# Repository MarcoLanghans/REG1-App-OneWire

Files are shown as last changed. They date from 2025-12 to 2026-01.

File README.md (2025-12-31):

Onewire Extension Card for OpenKNX REG1 BASE Device https://openknx.atlassian.net/wiki/spaces/OpenKNX/pages/7667822/OpenKNX+REG1+Basismodul (But you need the Case of the Universal Extension Version)
<br>
The Extension Card is no official created OpenKNX Hardware, so the usage is your personal risk. 
<br>
But it runs now since several days inside my person lab without any issues.

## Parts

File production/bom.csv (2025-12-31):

Designator | Footprint | Quantity | Value | LCSC Part #
C1, C10, C5, C6 | 0402 | 4 | 100nF
C2, C3, C4, C7 | 0402 | 4 | 10uF/6.3V | C15525
C8, C9 | 0402 | 2 | 0,1uF
D1 | DS9503P+ | 1 | DS9503P+ | C879660
D2 | D_SOD-323 | 1 | 1N5819WS | C191023
D4 | SOT-23-3 | 1 | ESDA5V3L | C502554
J1 | PinHeader_1x10_P2.54mm_Horizontal | 1 | REG1_App_Connector | C706873
R1, R11, R12, R3, R5, R6 | 0603 | 6 | 10K | C25804
R10, R9 | 0603 | 2 | 100 | C22775
R2, R4 | 0603 | 2 | 820 | C23253
R7, R8 | 0603 | 2 | 470 | C23179
U2 | SOT-23-5 | 1 | MIC2090-1YM5 | C625685
U3 | DS2484R+T | 1 | DS2484R+T | C124886
U4 | CA-IS3643HVW (C7422549) | 1 | CA-IS3643HVW
U5 | CA-IS3020G (C5156914) | 1 | CA-IS3020G

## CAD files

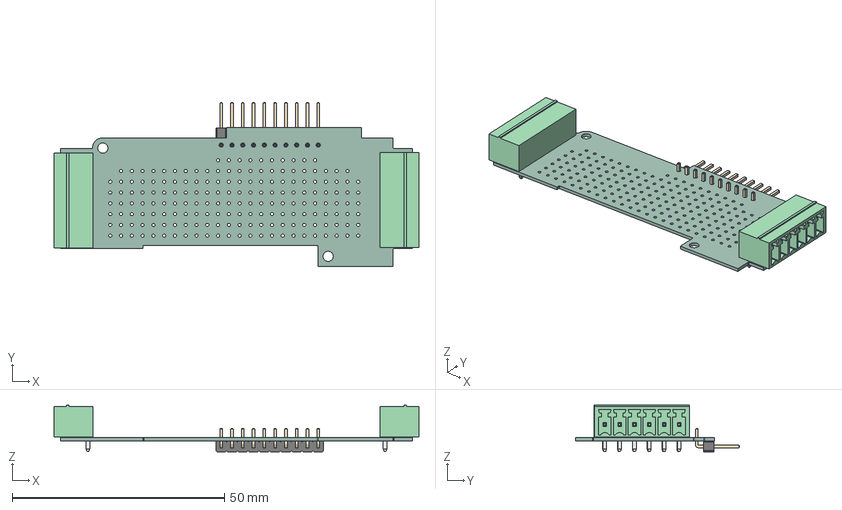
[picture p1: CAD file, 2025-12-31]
REG1-App-OneWire_V01.10.step
86.0 x 38.6 x 11.0 mm
MC_01x06_G_3_5mm x 2
PinHeader_1x10_P254mm_Horizontal
REG1-App-Universal_PCB

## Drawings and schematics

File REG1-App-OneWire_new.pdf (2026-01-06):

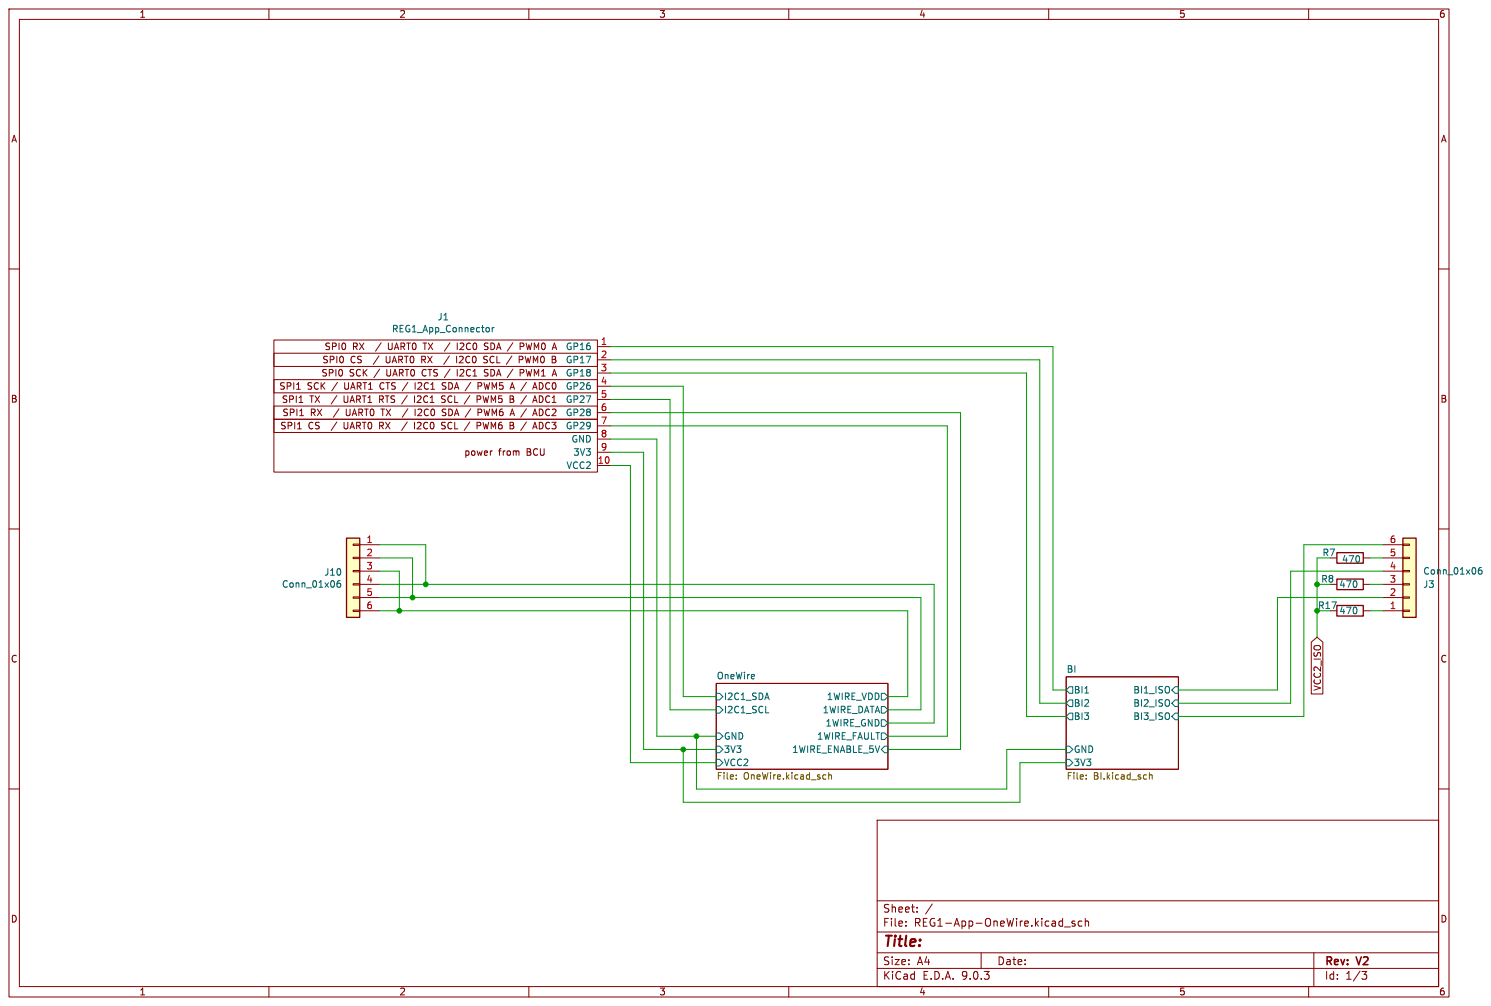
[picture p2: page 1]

Id: 1/3 Title: File: REG1-App-OneWire.kicad_sch Sheet: / 3V3 GND

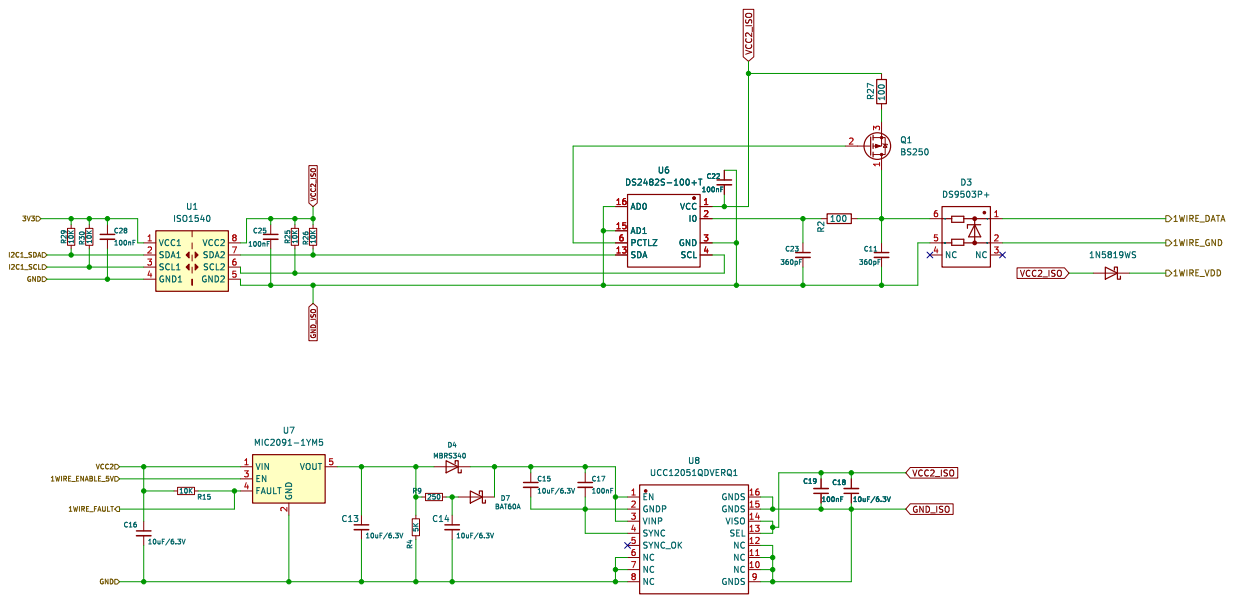
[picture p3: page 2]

Id: 2/3 Title: File: OneWire.kicad_sch Sheet: /OneWire/

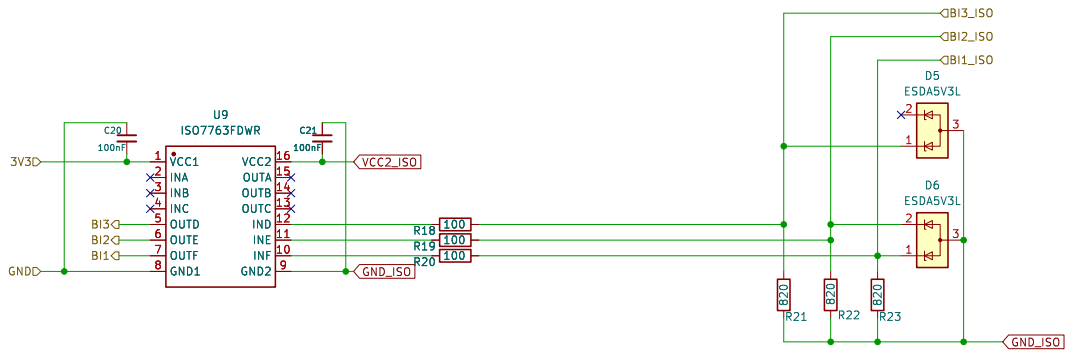
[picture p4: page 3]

Id: 3/3 Title: File: BI.kicad_sch Sheet: /BI/

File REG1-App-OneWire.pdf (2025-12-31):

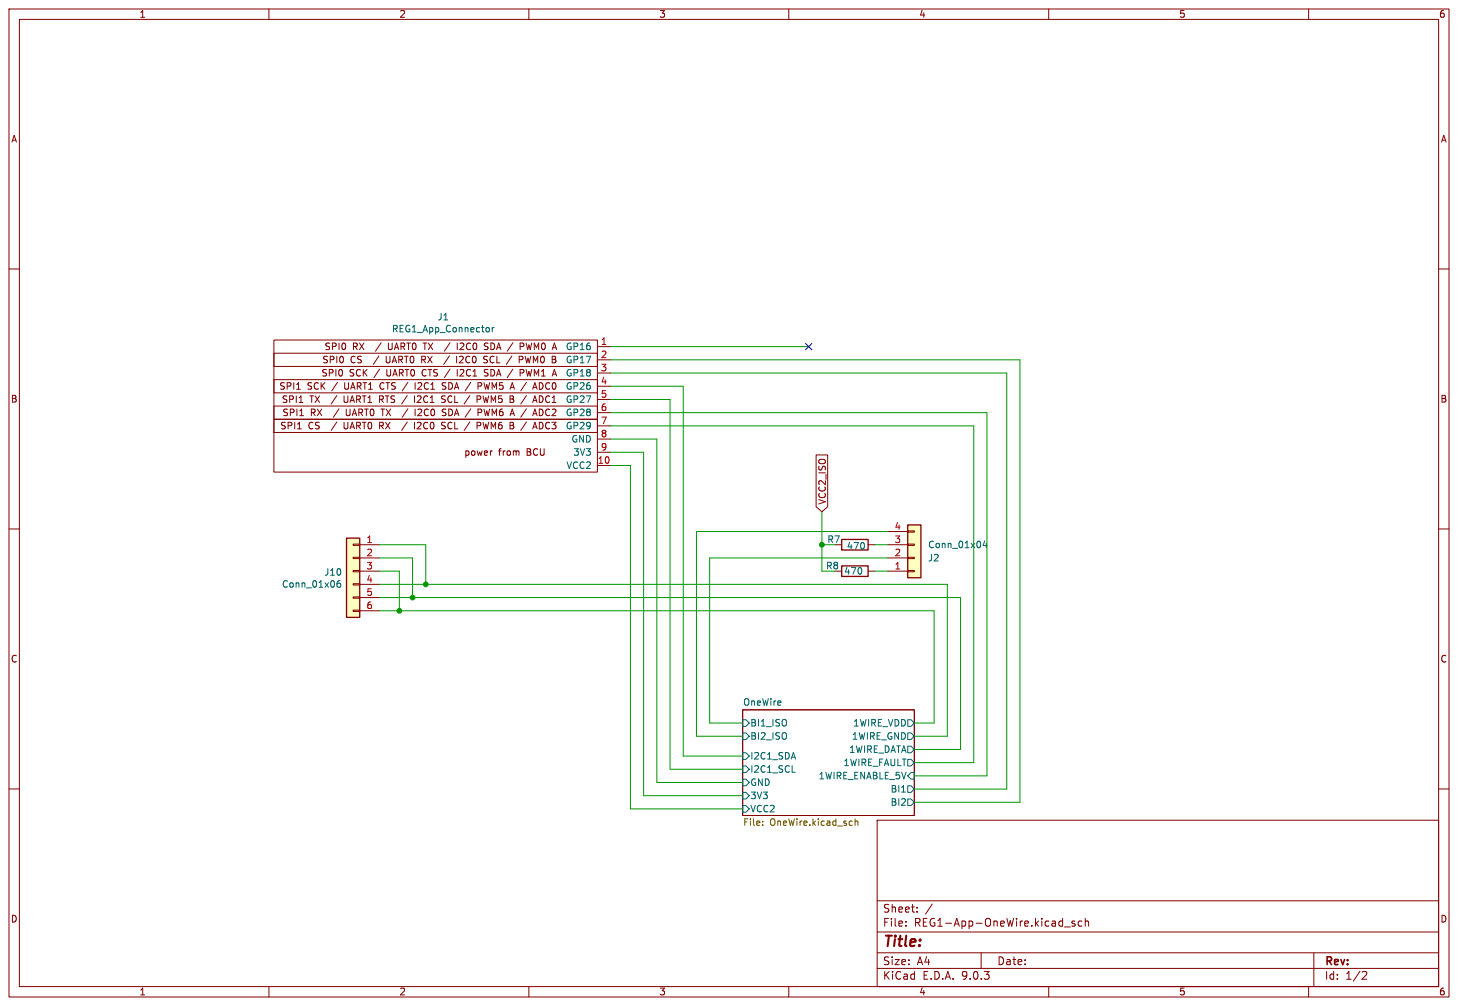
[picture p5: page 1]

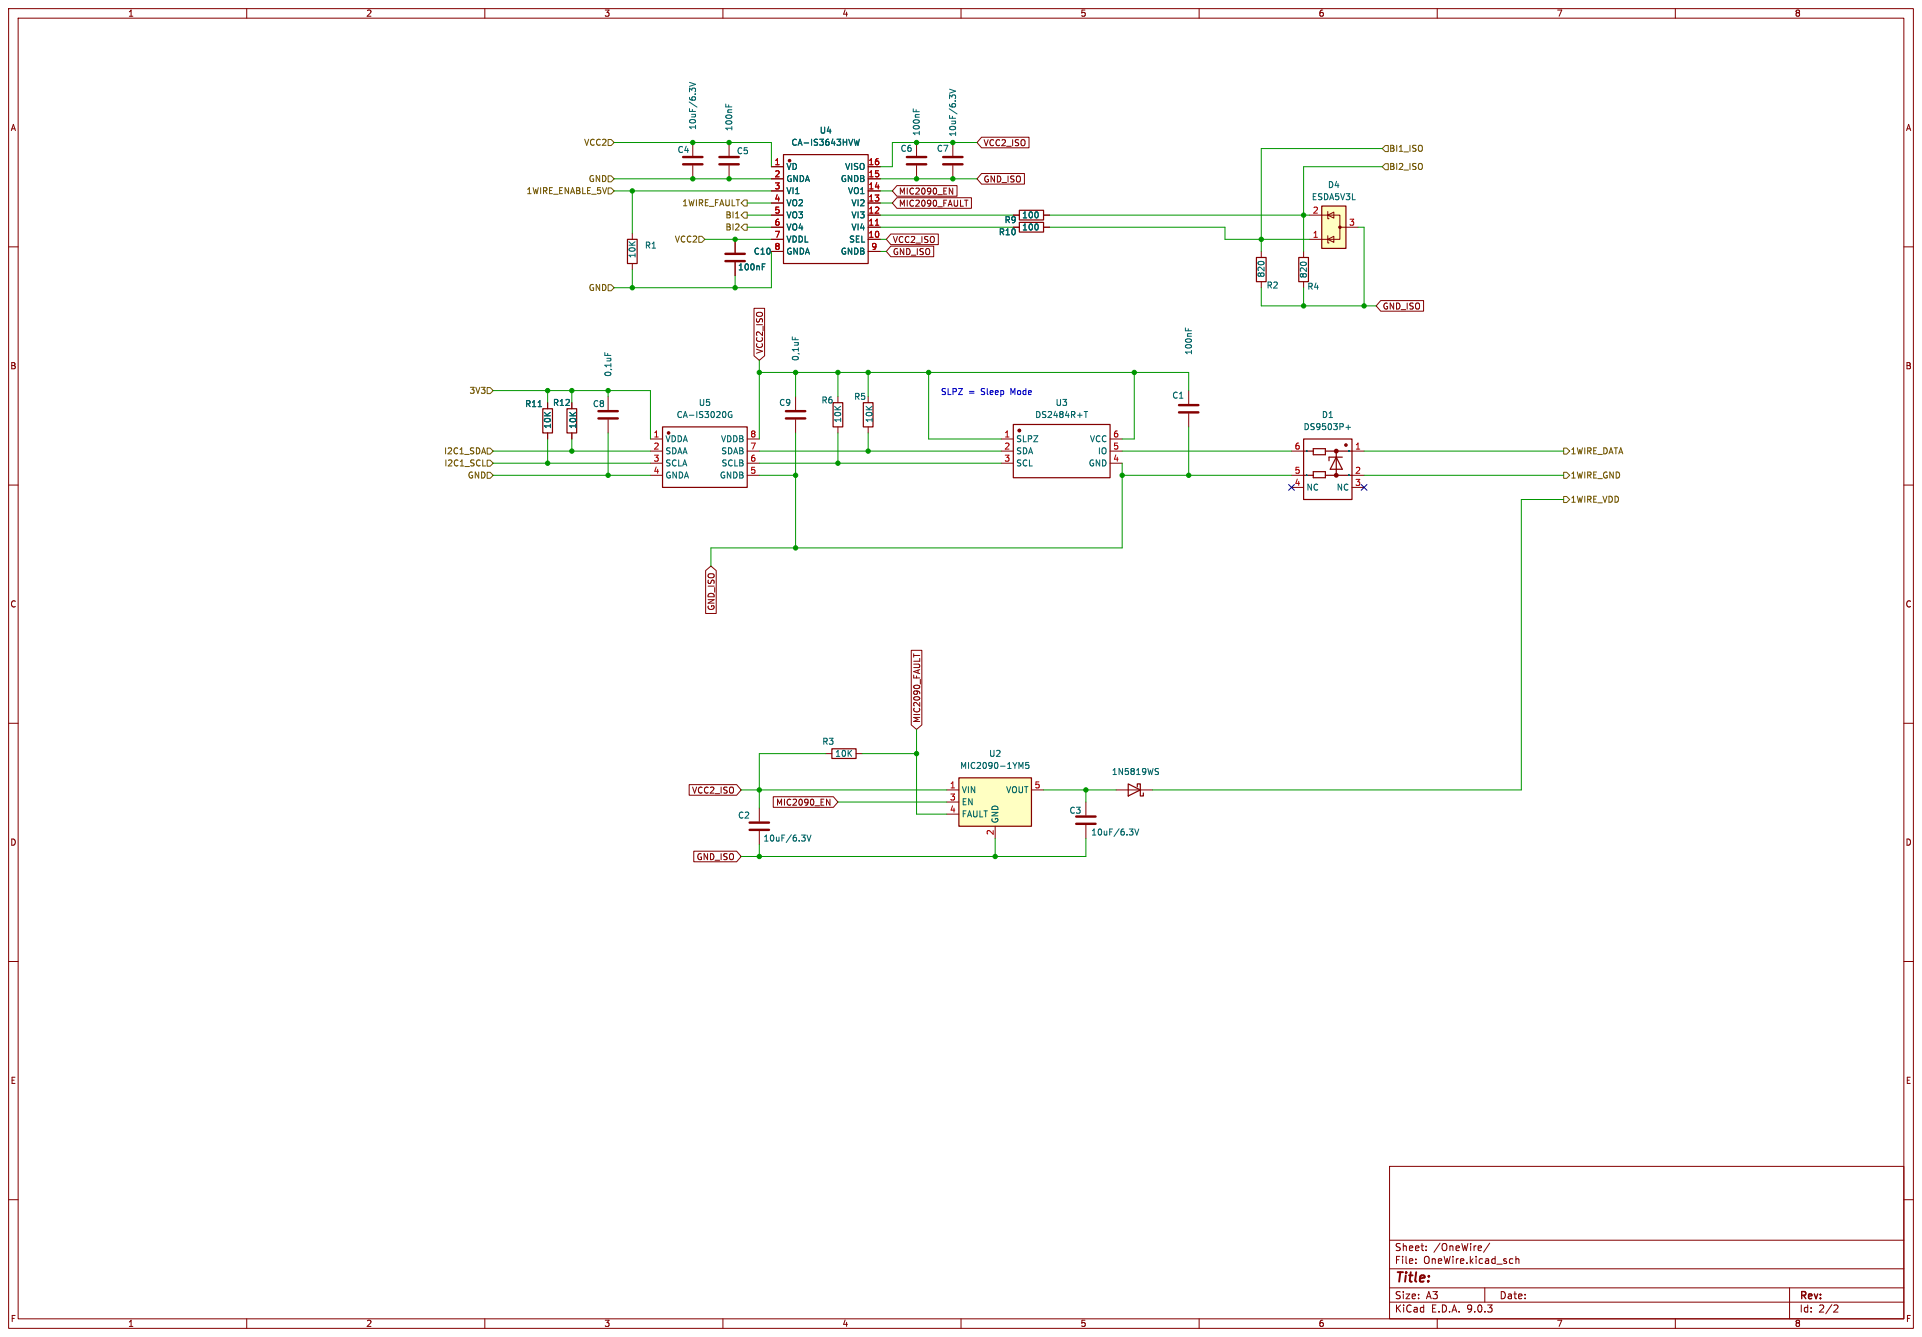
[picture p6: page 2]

Id: 2/2 Title: File: OneWire.kicad_sch Sheet: /OneWire/

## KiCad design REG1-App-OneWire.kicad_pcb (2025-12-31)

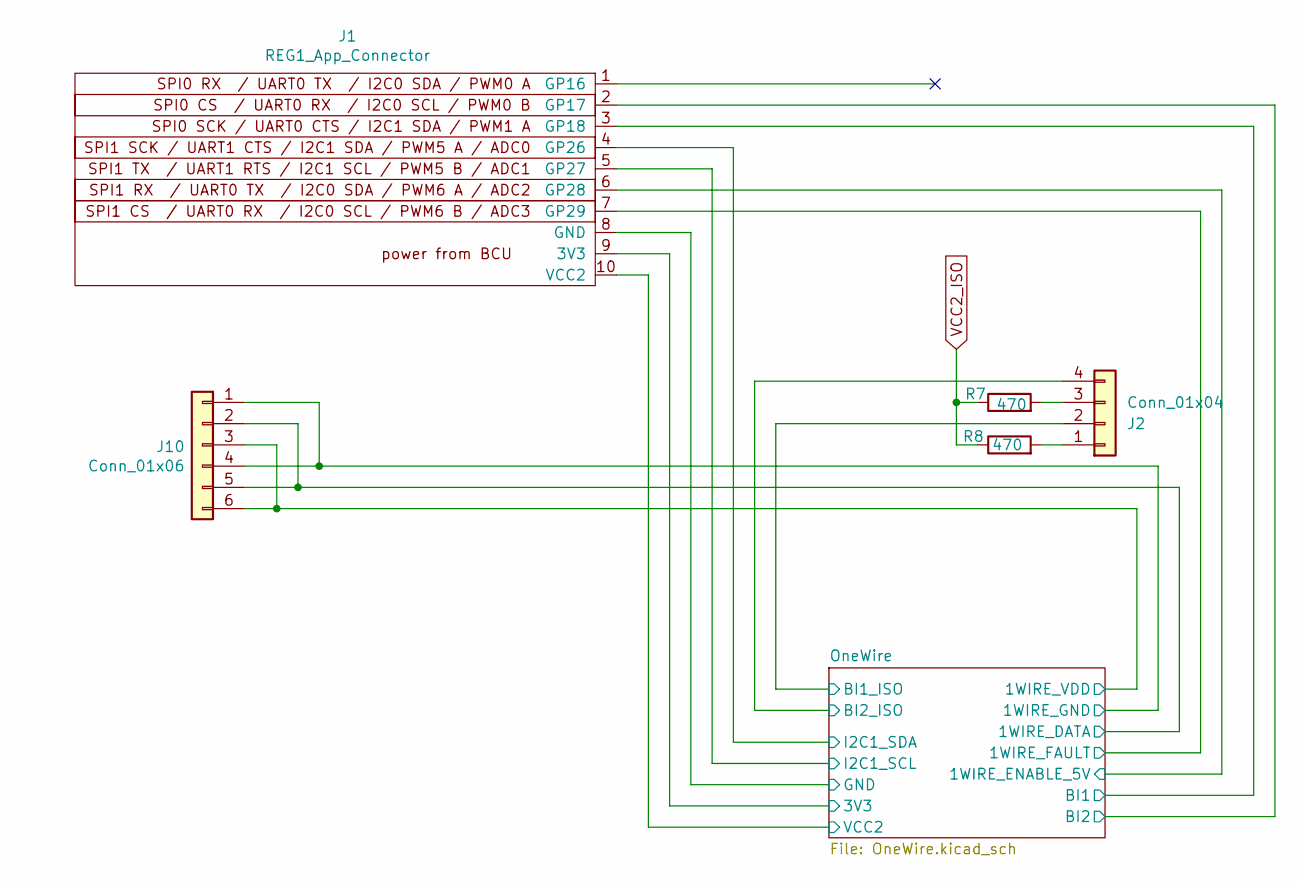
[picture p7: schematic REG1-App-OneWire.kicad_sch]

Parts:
J1: REG1_App_Connector; PinHeader_1x10_P2.54mm_Horizontal; LCSC C706873
J2: Conn_01x04; PhoenixContact_MC_1,5_4-G-3.5_1x04_P3.50mm_Horizontal
J10: Conn_01x06; PhoenixContact_MC_1,5_6-G-3.5_1x06_P3.50mm_Horizontal; LCSC C441175
R7, R8: 470; R_0603_1608Metric; MPN C23179

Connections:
/OneWire/1WIRE_DATA: J10.2, J10.5; also elsewhere on the board
/OneWire/1WIRE_ENABLE_5V: J1.6 (GP28); also elsewhere on the board
/OneWire/1WIRE_FAULT: J1.7 (GP29); also elsewhere on the board
/OneWire/1WIRE_GND: J10.1, J10.4; also elsewhere on the board
/OneWire/1WIRE_VDD: J10.3, J10.6; also elsewhere on the board
/OneWire/3V3: J1.9 (3V3); also elsewhere on the board
/OneWire/BI1: J1.3 (GP18); also elsewhere on the board
/OneWire/BI1_ISO: J2.2; also elsewhere on the board
/OneWire/BI2: J1.2 (GP17); also elsewhere on the board
/OneWire/BI2_ISO: J2.4; also elsewhere on the board
/OneWire/GND: J1.8 (GND); also elsewhere on the board
/OneWire/I2C1_SCL: J1.5 (GP27); also elsewhere on the board
/OneWire/I2C1_SDA: J1.4 (GP26); also elsewhere on the board
/OneWire/VCC2: J1.10 (VCC2); also elsewhere on the board
unnamed: J2.1, R8.2
unnamed: J2.3, R7.2
VCC2_ISO: R7.1, R8.1; also elsewhere on the board

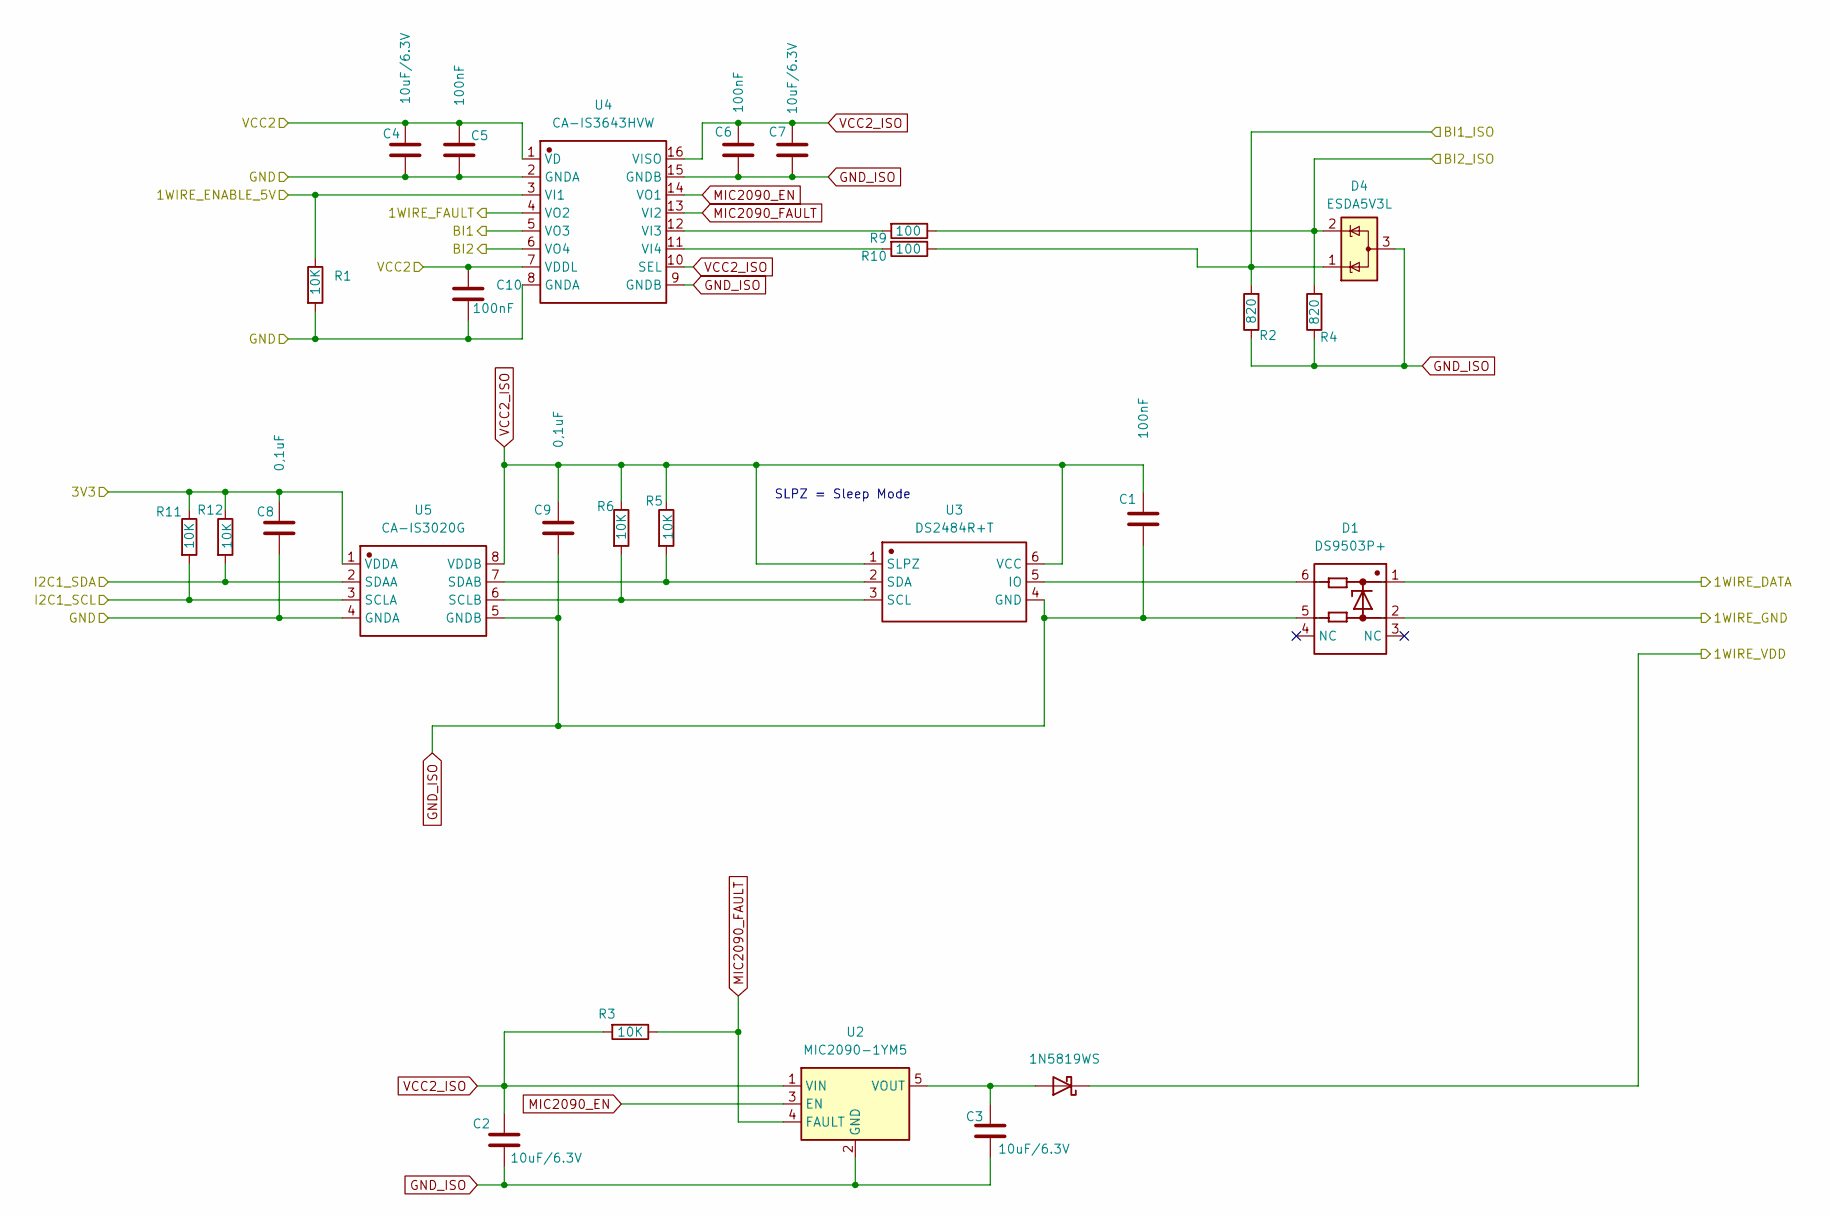
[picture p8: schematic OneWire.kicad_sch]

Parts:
C1, C5, C6, C10: 100nF; C_0402_1005Metric
C2, C3, C4, C7: 10uF/6.3V; C_0402_1005Metric; MPN C15525
C8, C9: 0,1uF; C_0402_1005Metric
D1: DS9503P+; Manufacturer Part DS9503P+
D2: 1N5819WS; D_SOD-323; MPN C191023
D4: ESDA5V3L; SOT-23-3; MPN C502554
R1, R3, R5, R6, R11, R12: 10K; R_0603_1608Metric; MPN C25804
R2, R4: 820; R_0603_1608Metric; MPN C23253
R9, R10: 100; R_0603_1608Metric; MPN C22775
U2: MIC2090-1YM5; SOT-23-5
U3: DS2484R+T; Manufacturer Part DS2484R+T
U4: CA-IS3643HVW; CA-IS3643HVW (C7422549); Manufacturer Part CA-IS3643HVW
U5: CA-IS3020G; CA-IS3020G (C5156914); Manufacturer Part CA-IS3020G

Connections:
/OneWire/1WIRE_DATA: D1.1; also elsewhere on the board
/OneWire/1WIRE_ENABLE_5V: R1.1, U4.3 (VI1); also elsewhere on the board
/OneWire/1WIRE_FAULT: U4.4 (VO2); also elsewhere on the board
/OneWire/1WIRE_GND: D1.2; also elsewhere on the board
/OneWire/1WIRE_VDD: D2.1 (K); also elsewhere on the board
/OneWire/3V3: C8.1, R11.1, R12.1, U5.1 (VDDA); also elsewhere on the board
/OneWire/BI1: U4.5 (VO3); also elsewhere on the board
/OneWire/BI1_ISO: D4.1 (K), R2.2, R10.1; also elsewhere on the board
/OneWire/BI2: U4.6 (VO4); also elsewhere on the board
/OneWire/BI2_ISO: D4.2 (K), R4.2, R9.1; also elsewhere on the board
/OneWire/GND: C4.2, C5.2, C8.2, C10.2, R1.2, U4.2 (GNDA), U4.8 (GNDA), U5.4 (GNDA); also elsewhere on the board
/OneWire/I2C1_SCL: R11.2, U5.3 (SCLA); also elsewhere on the board
/OneWire/I2C1_SDA: R12.2, U5.2 (SDAA); also elsewhere on the board
/OneWire/VCC2: C4.1, C5.1, C10.1, U4.1 (VD), U4.7 (VDDL); also elsewhere on the board
GND_ISO: C1.1, C2.2, C3.2, C6.1, C7.1, C9.2, D1.5, D4.3 (A), R2.1, R4.1, U2.2 (GND), U3.4 (GND), U4.9 (GNDB), U4.15 (GNDB), U5.5 (GNDB)
MIC2090_EN: U2.3 (EN), U4.14 (VO1)
MIC2090_FAULT: R3.1, U2.4 (FAULT), U4.13 (VI2)
unnamed: D1.6, U3.5 (IO)
unnamed: C3.1, D2.2 (A), U2.5 (VOUT)
unnamed: R6.2, U3.3 (SCL), U5.6 (SCLB)
unnamed: R5.2, U3.2 (SDA), U5.7 (SDAB)
unnamed: R9.2, U4.12 (VI3)
unnamed: R10.2, U4.11 (VI4)
VCC2_ISO: C1.2, C2.1, C6.2, C7.2, C9.1, R3.2, R5.1, R6.1, U2.1 (VIN), U3.1 (SLPZ), U3.6 (VCC), U4.10 (SEL), U4.16 (VISO), U5.8 (VDDB); also elsewhere on the board

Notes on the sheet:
SLPZ = Sleep Mode

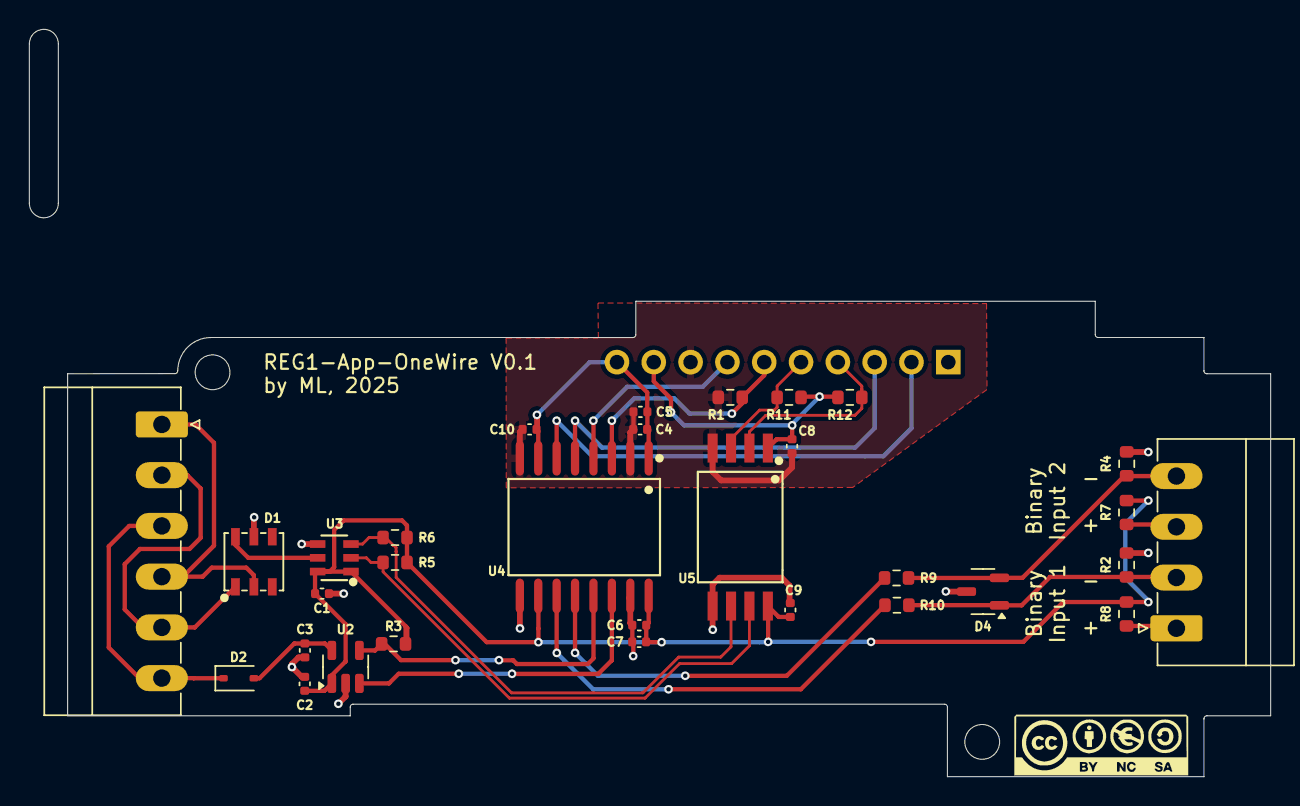
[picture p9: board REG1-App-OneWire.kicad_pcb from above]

Board: 2 copper layers, 83.0 x 32.8 mm, 33 parts (1 on the bottom side), 26 nets.

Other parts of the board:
G*: LOGO; CC-BY-NY-SA_12x4
